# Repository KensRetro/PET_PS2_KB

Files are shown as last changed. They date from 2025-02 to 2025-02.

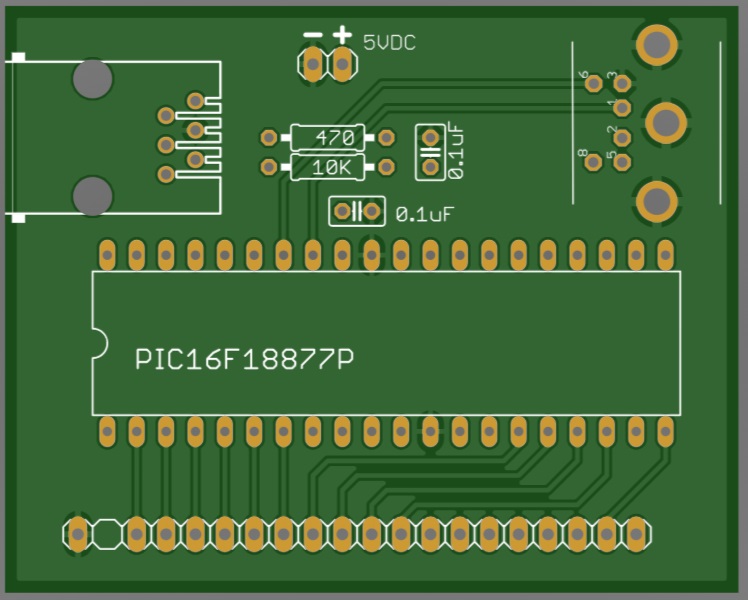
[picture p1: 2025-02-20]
Schematics/PCB.jpg

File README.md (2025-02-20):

# PET_PS2_KB
An adaptor to connect a PS2 keyboard to a to PET computer.  Plugs directly into the motherboard at the keyboard connector.  
Needs a 5V supply from a convenient place on the motherboard.  There is a ground pin on the KB connector so optionally connect
a ground to the power connector.  The modular jack on the board is optional - Used for programming and debugging the PIC 
program.

Uses a PIC16F18877 to do pretty much everything.

Operation:
MOST keys are translated to the PETS keyboard matrix, see * notes below.
Currently, only the GRAPHIC keyboard is supported, but it would only take a bit of editing to change the tables for a BUSINESS keyboard.

Special keys are as follows:

-- PS2 Key -> PET Key --
* ESC      -> RUN/STOP
* Tilde    -> Left Arrow
* TAB      -> RVS
* SCRLOK   -> (Reboots keyboard interface)***
* END      -> Clear Screen (shift-home)
* Shift 6  -> Up Arrow
* ALT      -> Shift to Graphic on double function keys (1-9 etc.)**
* L/R CTRL -> Hardware equivalnt of SHIFT keys*

Non PET keys are generally No Function

*The PS2 shift keys are  generally treated as a "Soft-Shift" and sent to the PET as needed when a second key is pressed.
If you need to press the SHIFT key alone on the PET use the CTRL key instead.
Limitations of the PS2 keyboard seem to block both SHIFT or CTRL being detected as pressed at the same time, so translating
this to the PET is not possible.  Other multi-key combinations may also not work, but generally it's pretty good.

**Example: to get the graphic on the ! key you need to press SHIFT-ALT-1  (SHIFT-1 for ! and ALT for graphic)

***Once in a while (usually while pressing many keys at once) a key press or release is not detected, pressing the SCROLL-LOCK 
key reboots the PIC and resets the keymap to no keys pressed, usually there's no effect to the PET

How It Works:
 
An interrupt-on-change routine (The PET sets a ROW to read) sets outputs (Columns) for the PET to read back as keypresses.  
A main loop is created to catch bytes from the PS2 keyboard,
Once a PS2 byte is received, it is buffered until bytes stop coming in (A PS2 keypress generates between 2 and 6 bytes)
Once timer2 runs out (which is reset every byte receive, and whose period is slightly longer that the byte to byte interval)
It is assumed the PS2 keyboard has completed sending a Key status change.  The buffer is examined and the appropriate bits are set 
in the memory map setup to represent the PET's keyboard matrix.

Note: routines are optimized for speed, not space, this is to ensure the response is fast enough to suit the PET's 
normal keyboard scan speed

Currently supports GRAPHICS keyboard ONLY - tables would need updating for business style KB

DISCLAIMER: All information is provided 'AS-IS" for informational purposes only.
I have tried to be as accurate as possible but that doesn't mean there are no mistakes. 
Any errors or omissions etc. are your own responsibility.  
There is no Warranty or guarantee of any kind. See licence for details.

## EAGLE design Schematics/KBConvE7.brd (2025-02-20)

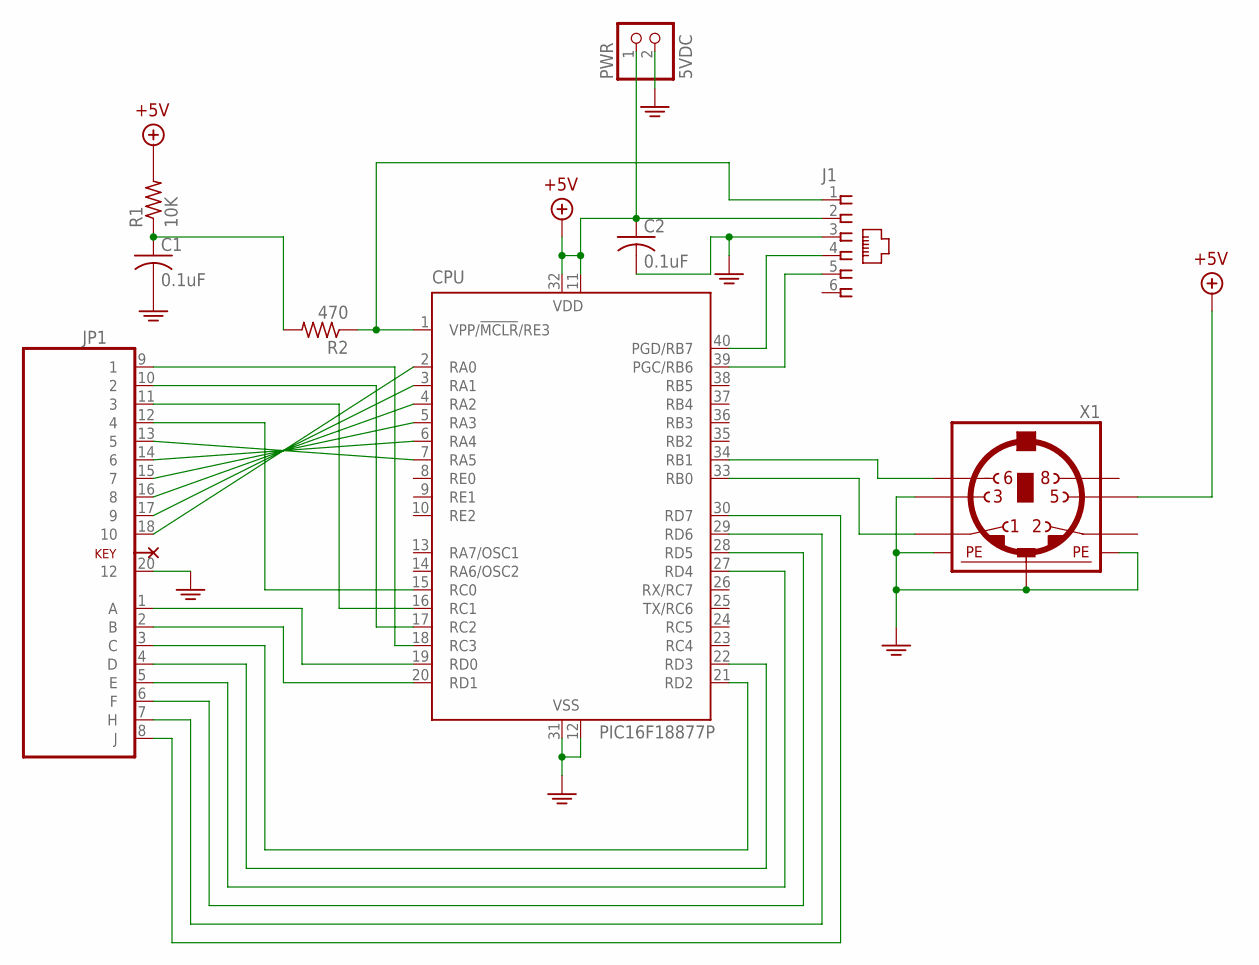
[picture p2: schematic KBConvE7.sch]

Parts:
C1, C2: 0.1uF; C025-025X050
CPU: PIC16F18877P; DIL40
J1: 520250-3
JP1: PET_KEYBOARD
PWR: 5VDC; 1X02
R1: 10K; 0207/10
R2: 470; 0207/10
X1: MINI_DIN_6; M_DIN6

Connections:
+5V: C2.1, CPU.11 (VDD), CPU.32 (VDD), J1.2, PWR.1, R1.2, X1.5
GND: C1.2, C2.2, CPU.12 (VSS), CPU.31 (VSS), J1.3, JP1.20 (12), PWR.2, X1.3, X1.SH1 (PE1), X1.SH2 (PE2), X1.SH3 (PE3)
unnamed: CPU.2 (RA0), JP1.18 (10)
unnamed: CPU.3 (RA1), JP1.17 (9)
unnamed: CPU.4 (RA2), JP1.16 (8)
unnamed: CPU.5 (RA3), JP1.15 (7)
unnamed: CPU.6 (RA4), JP1.14 (6)
unnamed: CPU.7 (RA5), JP1.13 (5)
unnamed: CPU.15 (RC0), JP1.12 (4)
unnamed: CPU.16 (RC1), JP1.11 (3)
unnamed: CPU.17 (RC2), JP1.10 (2)
unnamed: CPU.18 (RC3), JP1.9 (1)
unnamed: CPU.19 (RD0), JP1.1 (A)
unnamed: CPU.20 (RD1), JP1.2 (B)
unnamed: CPU.21 (RD2), JP1.3 (C)
unnamed: CPU.22 (RD3), JP1.4 (D)
unnamed: CPU.27 (RD4), JP1.5 (E)
unnamed: CPU.33 (RB0), X1.1
unnamed: CPU.28 (RD5), JP1.6 (F)
unnamed: CPU.29 (RD6), JP1.7 (H)
unnamed: CPU.30 (RD7), JP1.8 (J)
unnamed: C1.1, R1.1, R2.2
unnamed: CPU.39 (PGC/RB6), J1.5
unnamed: CPU.40 (PGD/RB7), J1.4
unnamed: CPU.34 (RB1), X1.6
unnamed: CPU.1 (VPP/!MCLR!/RE3), J1.1, R2.1

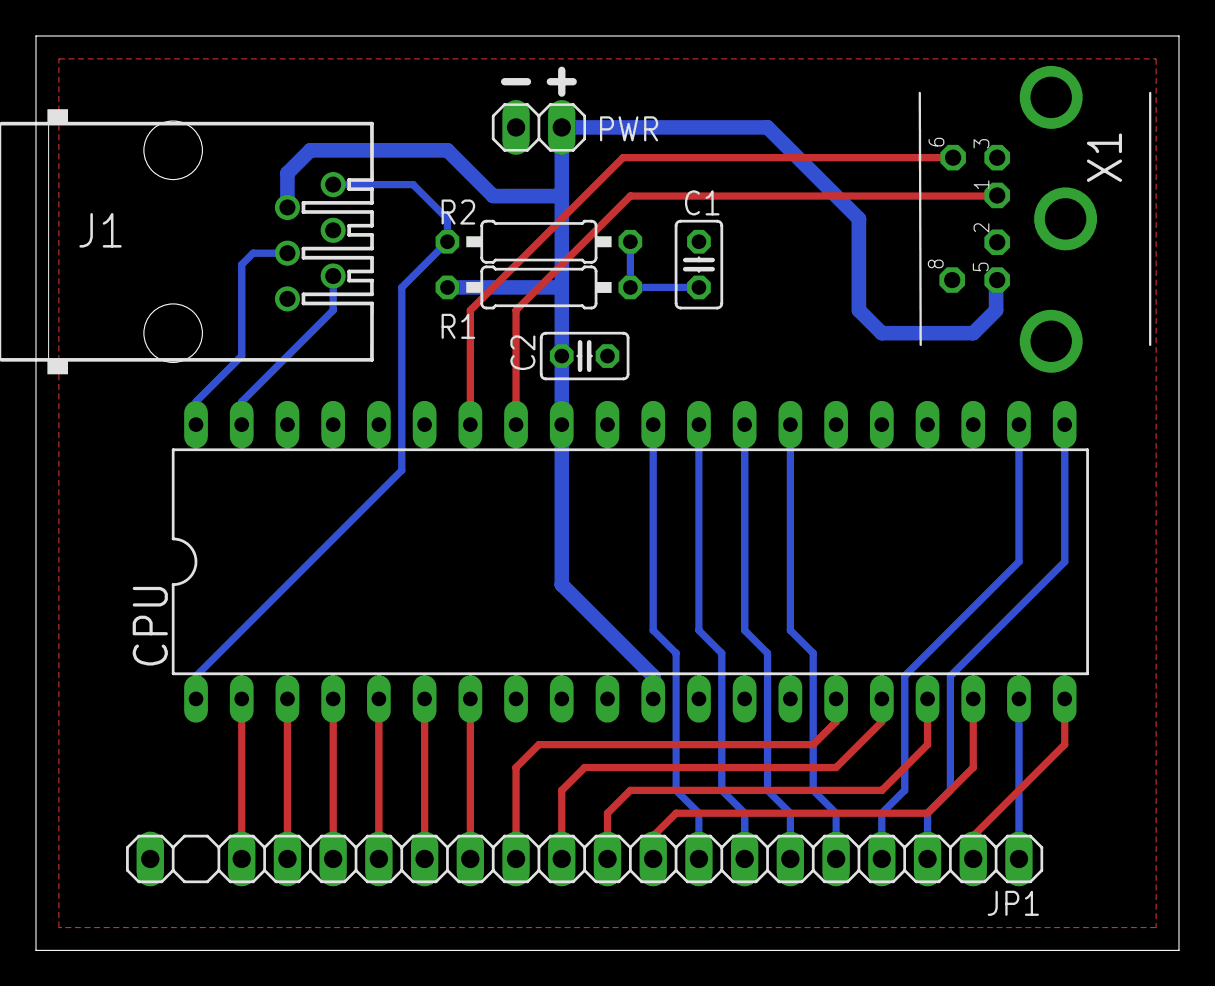
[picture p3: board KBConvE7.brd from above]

Board: 2 copper layers, 63.5 x 50.8 mm, 9 parts (0 on the bottom side), 26 nets.

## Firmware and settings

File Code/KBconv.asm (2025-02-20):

; Source for PS2 Keyboard Decoder 

    
;<editor-fold defaultstate="collapsed" desc="Config / Notes">    
    list p=16F18877, R=DEC 

; PIC16F18877 Configuration Bit Settings

#include "p16f18877.inc"

    __CONFIG _CONFIG1, _FEXTOSC_OFF & _RSTOSC_HFINT32 & _CLKOUTEN_OFF & _CSWEN_OFF & _FCMEN_OFF
    __CONFIG _CONFIG2, _MCLRE_ON & _PWRTE_OFF & _LPBOREN_OFF & _BOREN_ON & _BORV_HI & _ZCD_OFF & _PPS1WAY_OFF & _STVREN_OFF
    __CONFIG _CONFIG3, _WDTCPS_WDTCPS_31 & _WDTE_OFF & _WDTCWS_WDTCWS_7 & _WDTCCS_HFINTOSC
    __CONFIG _CONFIG4, _WRT_OFF & _SCANE_not_available & _LVP_ON
    __CONFIG _CONFIG5, _CP_OFF & _CPD_OFF
    ; faked - fix WDT ON / DEBUG OFF /CP ALL 
    
    ; CLOCK: 32 Mhz
    
    errorlevel -302 ; Turn off banking message

;-------------------------------------------------------------
; Version History :
;		
;
; How It Works:
; 
; An interrupt-on-change routine (The PET sets a ROW to read) sets outputs (Columns) for the PET to read back as keypresses.  
; A main loop is created to catch bytes from the PS2 keyboard,
; Once a PS2 byte is received, it is buffered until bytes stop coming in (A PS2 keypress generates between 2 and 6 bytes)
; Once timer2 runs out (which is reset every byte receive, and whose period is slightly longer that the byte to byte interval)
; It is assumed the PS2 keyboard has completed sending a Key status change.  The buffer is examined and the appropriate bits are set 
; in the memory map setup to represent the PET's keyboard matrix.
;
; Note: routines are optimized for speed, not space, this is to ensure the response is fast enough to suit the PET's 
; normal keyboard scan speed
;
; Currently supports GRAPHICS keyboard ONLY - tables would need updating for business style KB
;    
    
;</editor-fold>		
;<editor-fold defaultstate="collapsed" desc="Variables">
;-------------------------------------------------------------
; VARIABLES
    
	CBLOCK 0x020
	C0			; Don't move the C registes - They are referred to indirectly
	C1			; this is the PET column corresponding to the requested row
	C2
	C3
	C4
	C5
	C6
	C7
	C8
	C9
	KBDcnt			; keyboard scan bit counter
	KBD			; keyboard data register
	FLAGreg
	FLAG2reg
	SHreg
	BIT
	COLtmp
	NBIT
	pausehi
	pauselo
	d1
	d2
	bitcnt
	Sbyte
	parcalc
	temp
	BufPtr
	Buffer
	Buffer1	
	Buffer2	
	Buffer3
	Buffer4
	Buffer5	
	Buffer6
	Buffer7
	Buffer8
	Buffer9	
	Buffer10
	Buffer11
	Buffer12
	Buffer13
	Buffer14
	Buffer15
	BufferPad
	TEMP
	mtmp
	ENDC 

	CBLOCK 0x07F
	Count
	;**** Delay Routine Variables  ***
	 dx
	 dy	
	ENDC
	
	; Per Keystroke  flags
	#define	RELflag	FLAGreg,0	; release flag (0xF0)
	#define	SPflag	FLAGreg,1	; Special Character Flag - CRSR or other
	
	; held flags
	#define	LSHflag  SHreg,0	; shift flag (0x12)
	#define	RSHflag  SHreg,1	; shift flag (0x59)
	#define Slock	 SHreg,2	; Shift Lock state	
	
	#define	ALTflag	 FLAG2reg,0	; ALT flag   (0x11)
	#define	CTRLflag FLAG2reg,1	; CTRL flag  (0x14)
	#define	KBDflag	 FLAG2reg,2	; keyboard data reception flag	
	#define	OldClk   FLAG2reg,3	; Last state of keyboard clk
	#define	NewClk   FLAG2reg,4	; Current state of keyboard clk	
	#define	SKPS	 FLAG2reg,5	; Skip processing shift
	
	; End Variables
;-------------------------------------------------------------
;</editor-fold>
;<editor-fold defaultstate="collapsed" desc="Constants">
; CONSTANTS
	;NONE
; End Constants

;</editor-fold>
;<editor-fold defaultstate="collapsed" desc="Macros">	
weq macro val,dest	; if W = val then goto dest
 
    sublw val
    btfsc STATUS,Z
    goto dest
    
    endm

wne macro val,dest	; if W <> val then goto dest
 
    sublw val
    btfss STATUS,Z
    goto dest
    
    endm    

wgt macro val,dest	; if W > val then goto dest
 
    sublw val
    btfss STATUS,C
    goto dest
    
    endm 
    
wlte macro val,dest	; if W <= val then goto dest
 
    sublw val 
    btfsc STATUS,C
    goto dest
    
    endm
;</editor-fold>    
;<editor-fold defaultstate="collapsed" desc="Port / Pin Definitions">
;-------------------------------------------------------------
    ; inputs use PORTX  Outputs use LATX
    #define Col9			PORTA,0   ; ordered this way to ease PCB layout
    #define Col8			PORTA,1	 
    #define Col7			PORTA,2
    #define Col6			PORTA,3
    #define Col5			PORTA,4  
    #define Col4			PORTA,5
    ;#define				PORTA,6 
    ;#define				PORTA,7

    #define KBDdatapin			PORTB,0	 
    #define KBDclkpin			PORTB,1
    ;#define				PORTB,2
    ;#define				PORTB,3
    #define test			LATB,4
    ;#define				PORTB,5
    ;#define PGC			PORTB,6	 
    ;#define PGD			PORTB,7  

    #define KBDdatatris			TRISB,0 
    #define KBDclktris			TRISB,1    
    #define KBDdataout			LATB,0
    #define KBDclkout			LATB,1
    
    #define Col3			PORTC,0	 
    #define Col2			PORTC,1
    #define Col1			PORTC,2
    #define Col0			PORTC,3
;    #define DLATCH			LATC,4  
;    #define CA1			LATC,5
;    #define DIAG			LATC,5
;    #define TX				LATC,6
;    #define RX				PORTC,7
;
;    PORTD is ROW outputs    
;    #define ADD4			LATD,0  
;    #define ADD5			LATD,1
;    #define ADD6			LATD,2
;    #define ADD7			LATD,3
;    #define ADD8			LATD,4
;    #define ADD9			LATD,5
;    #define ADD10			LATD,6
;    #define MODE			PORTD,7
	
;    #define NEN			LATE,0  
;    #define NOE			LATE,1  
;    #define NWE			LATE,2	
 
;</editor-fold>
;<editor-fold defaultstate="collapsed" desc="Start / IRQ Vectors">	
; Reset Vector
    org	 0x0000
    nop
    goto	start
    nop
	
; ---------------- 
; Interrupt Stuff
; ---------------- 
; Interrupt Vector
	 
    org 0x0004
    goto interupt
    nop
    nop
;</editor-fold>
;<editor-fold defaultstate="collapsed" desc="IRQ Routine">	
	
; ----------------	
; IRQ ROUTINE	
; ----------------
interupt			; IOC interrupt, PET is asking for a certain row in the matrix
    
    call UPDPET

    banksel IOCAF
    clrf IOCAF
    clrf IOCCF
    banksel PIR0
    clrf PIR0
    ;bcf PIR0,IOCIF
    banksel PORTA
    
    retfie
   
;</editor-fold>
;<editor-fold defaultstate="collapsed" desc="Update PET's Row/Colunm">    
UPDPET
    
    banksel PORTA
    btfss Col1
    goto Cx1
    btfss Col2
    goto Cx2
    btfss Col3
    goto Cx3
    btfss Col4
    goto Cx4
    btfss Col5
    goto Cx5
    btfss Col6
    goto Cx6
    btfss Col7
    goto Cx7
    btfss Col8
    goto Cx8
    btfss Col9
    goto Cx9
    btfss Col0
    goto Cx0
    movlw 0xFF
    movwf LATD
    goto fin
Cx0 
    movfw C0
    movwf LATD
    goto fin
Cx1 
    movfw C1
    movwf LATD
    goto fin   
Cx2 
    movfw C2
    movwf LATD
    goto fin
Cx3 
    movfw C3
    movwf LATD
    goto fin
Cx4 
    movfw C4
    movwf LATD
    goto fin
Cx5 
    movfw C5
    movwf LATD
    goto fin
Cx6 
    movfw C6
    movwf LATD
    goto fin
Cx7 
    movfw C7
    movwf LATD
    goto fin
Cx8 
    movfw C8
    movwf LATD
    goto fin
Cx9 
    movfw C9
    movwf LATD
fin
    return
;</editor-fold>
    
start
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
